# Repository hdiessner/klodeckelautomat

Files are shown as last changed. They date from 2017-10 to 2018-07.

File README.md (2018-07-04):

# klodeckelautomat
This project serves the purpose to provide remote control of telescope covers that prevent dust from covering the front lense of telescopes.

Hardware requirements:
- Arduino
- Servo motors (one for each moving cover)
- Cover material for covering the front opening of the telescope
- Mounting material to attach the servo to the dew shield of the telescope
- Housing for Arduino
- push buttons for each cover if manual operation is wanted

Software:
- platformio project with code for the Arduino
- .py Python script to control open / close operations via command line
- .html front-end to use a web browser to open / close the cover

# Install python part
 1. Set Port in Winkergrabbe.py
 2. Optional: setup virtuelenv
 3. pip install -r requirements.txt
 4. python Winkergrabbe.py

# Serial commands

| ID | Data | Description |
|----|---|---|
|  0 | Text | Data Acknowledge |
|  1 | Text | Error |
|  2 | Text | Debug Messages |
|  3 | (0..7), (0..255)  | Set Servo x to y |
|  4 | (0..7), State | Store Servo x as pos |
|  5 | (0..2)  New state | Change State |
|  6 | (0..2), State | Telescope to pos |

| ID | State |
|----|---|
| 0  | Close |
| 1  | Open |
| 2  | Bahtinov  |
| 3  | Undefined |

# Pinout

| Pin | Description |
|-----|---|
| 2 | Button 0 |
| 3 | Button 1 |
| 4 | Button 2 |
| 5 | OE |
| A4  | SDA | 
| A5  | SCL |

# Servo description

| Num | Telescope | Purpose |
|-----|---|---|
| 0 | 0 | Cover |
| 1 | 0 | Bahtinov |
| 2 | 1 | Cover Left |
| 3 | 1 | Cover Right |
| 4 | 1 | Bahtinov Left  |
| 5 | 1 | Bahtinov Right |
| 6 | 2 | Cover |
| 7 | 2 | Bahtinov |

Addition in October 2017:
- 3D sketch for 3D printing of a telescope clamp that attaches to the dew shield of an AstroPhysics Starfire 155EDF and that provides the hosuing of a servo.

https://github.com/thijse/Arduino-CmdMessenger/issues/27

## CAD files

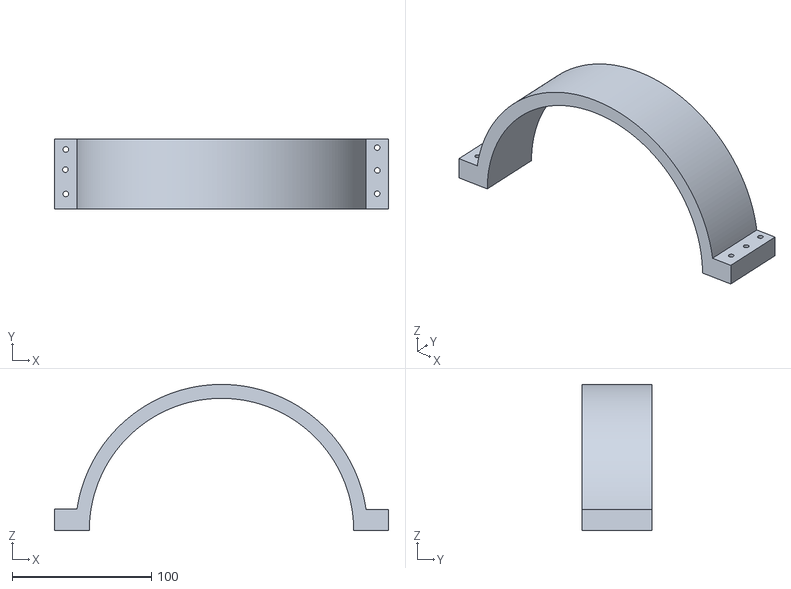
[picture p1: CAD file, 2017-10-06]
3D Design/Starfire155_Clamp_Bottom.stl
240.0 x 50.0 x 105.0

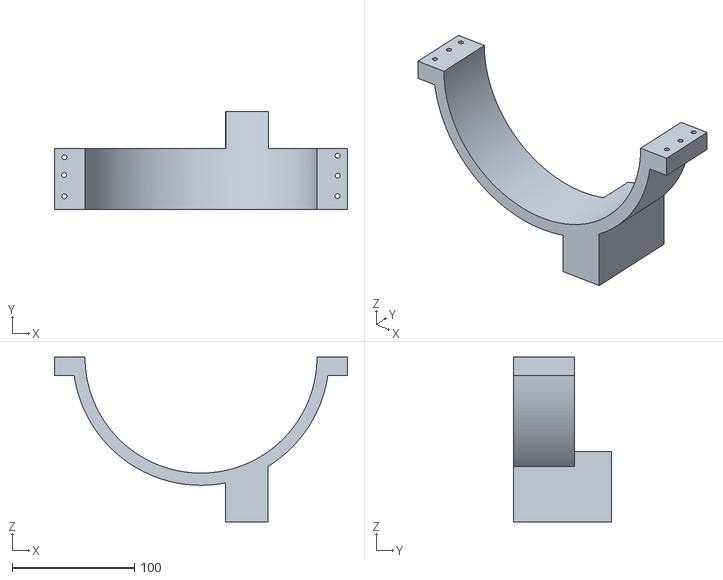
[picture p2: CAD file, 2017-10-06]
3D Design/Starfire155_Clamp_Motor.stl
240.0 x 80.0 x 135.0

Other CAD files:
3D Design/Scopeclamp v3 Motor v3.f3d

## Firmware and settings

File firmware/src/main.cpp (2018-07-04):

#include <Wire.h>
#include <EEPROM.h>
#include <Arduino.h>
#include <CmdMessenger.h>
#include <Adafruit_PWMServoDriver.h>

#define NUM_TELESCOPES   3
#define NUM_SERVOS       8
#define MOVE_WAIT_TIME 800

#define SWITCH_TELE0     2 
#define SWITCH_TELE1     3   
#define SWITCH_TELE2     4

#define OE_PIN           5   

uint16_t                positionsClosed[NUM_SERVOS] = {};
uint16_t                positionsOpen[NUM_SERVOS]   = {};
uint16_t                positionsSet[NUM_SERVOS]    = {};
uint8_t                 telescopeState[3]           = {0, 0, 0}; 
Adafruit_PWMServoDriver pwm                         = Adafruit_PWMServoDriver();
CmdMessenger            cmdMessenger                = CmdMessenger(Serial, ',', ';'); 

enum{                //      Closed     Open
  kAcknowledge,      // 0 
  kError,            // 1
  kDebug,            // 2
  kSetServo,         // 3   3,1,150;     3,1,400;
  kStoreServo,       // 4   4,1,0;       4,1,1;
  kStateChange,      // 5
  kTelescopePosition // 6   6,0,0;       6,0,1;    6,0,2;
};

void storePositions(){
  uint8_t  ee = 0;
  uint8_t* p  = (uint8_t*)(void*)&positionsClosed;

  for (uint8_t i = 0; i < sizeof(positionsClosed); i++){
      EEPROM.write(ee++, *p++);
  }

  ee = 100;
  p  = (uint8_t*)(void*)&positionsOpen;

  for (uint8_t i = 0; i < sizeof(positionsOpen); i++){
      EEPROM.write(ee++, *p++);
  }
  
}

void loadPositions(){

  uint8_t  ee = 0;
  uint8_t* p  = (uint8_t*)(void*)&positionsClosed;

  for (uint8_t i = 0; i < sizeof(positionsClosed); i++){
    *p++ = EEPROM.read(ee++);
  }

  ee = 100;
  p  = (uint8_t*)(void*)&positionsOpen;

  for (uint8_t i = 0; i < sizeof(positionsOpen); i++){
    *p++ = EEPROM.read(ee++);
  }

  // Middel state, we don't know jet
  for (uint8_t i = 0; i < NUM_SERVOS; i++){
    positionsSet[i] = 300; 
  }  

}

void OnSetServo(){
    cmdMessenger.sendCmd(kDebug, "SetServo called");
    uint8_t  servo      = cmdMessenger.readInt16Arg(); 
    uint16_t position   = cmdMessenger.readInt16Arg();
    positionsSet[servo] = position;
    pwm.setPWM(servo, 0, position);
    cmdMessenger.sendCmd(kAcknowledge, "StoreServo moved");
}

void OnStoreServo(){
    cmdMessenger.sendCmd(kDebug, "StoreServo called");
    uint8_t servo = cmdMessenger.readInt16Arg();
    uint8_t state = cmdMessenger.readInt16Arg();

    if (state == 0) {
      positionsClosed[servo] = positionsSet[servo];
    }

    if (state == 1) {
      positionsOpen[servo] = positionsSet[servo];    
    }

    storePositions();
    cmdMessenger.sendCmd(kAcknowledge, "StoreServo stored");
}

void moveToState(uint8_t telescope, uint8_t state){

  if (telescope == 0) {

    if (state == 0){                        // Close
      cmdMessenger.sendCmdStart(kStateChange);  
      cmdMessenger.sendCmdArg(0);    
      cmdMessenger.sendCmdArg(0);    
      cmdMessenger.sendCmdEnd();
      pwm.setPWM(1, 0, positionsOpen[1]);   // Open Bahtinov 
      delay(MOVE_WAIT_TIME);
      pwm.setPWM(0, 0, positionsClosed[0]); // Close Cover 
      delay(MOVE_WAIT_TIME);
      pwm.setPWM(1, 0, positionsClosed[1]); // Close Bahtinov 
      telescopeState[0] = 0;
      
    } else if (state == 1){                 // Open
      cmdMessenger.sendCmdStart(kStateChange);  
      cmdMessenger.sendCmdArg(0);    
      cmdMessenger.sendCmdArg(1);    
      cmdMessenger.sendCmdEnd();
      pwm.setPWM(1, 0, positionsOpen[1]);   // Open Bahtinov
      delay(MOVE_WAIT_TIME);
      pwm.setPWM(0, 0, positionsOpen[0]);   // Open Cover
      telescopeState[0] = 1;

    } else if (state == 2) {                // Bahtinov
      cmdMessenger.sendCmdStart(kStateChange);  
      cmdMessenger.sendCmdArg(0);    
      cmdMessenger.sendCmdArg(2);    
      cmdMessenger.sendCmdEnd();
      pwm.setPWM(1, 0, positionsOpen[1]);   // Open Bahtinov make sure its away
      delay(MOVE_WAIT_TIME);
      pwm.setPWM(0, 0, positionsOpen[0]);   // Open cover
      delay(MOVE_WAIT_TIME);
      pwm.setPWM(1, 0, positionsClosed[1]); // Close Bahtinov 
      telescopeState[0] = 2;
    }

  }

  if (telescope == 1) {

    if (state == 0){                        // Close
      cmdMessenger.sendCmdStart(kStateChange);  
      cmdMessenger.sendCmdArg(1);    
      cmdMessenger.sendCmdArg(0);    
      cmdMessenger.sendCmdEnd();
      pwm.setPWM(4, 0, positionsOpen[4]);   // Open Bahtinov 
      pwm.setPWM(5, 0, positionsOpen[5]);   // Open Bahtinov 
      delay(MOVE_WAIT_TIME);
      pwm.setPWM(2, 0, positionsClosed[2]); // Close Cover 
      pwm.setPWM(3, 0, positionsClosed[3]); // Close Cover 
      delay(MOVE_WAIT_TIME);
      pwm.setPWM(4, 0, positionsClosed[4]); // Close Bahtinov 
      pwm.setPWM(5, 0, positionsClosed[5]); // Close Bahtinov 
      telescopeState[1] = 0;

    } else if (state == 1){                // Open
      cmdMessenger.sendCmdStart(kStateChange);  
      cmdMessenger.sendCmdArg(1);    
      cmdMessenger.sendCmdArg(1);    
      cmdMessenger.sendCmdEnd();
      pwm.setPWM(4, 0, positionsOpen[4]);   // Open Bahtinov make sure its away
      pwm.setPWM(5, 0, positionsOpen[5]);   // Open Bahtinov make sure its away
      delay(MOVE_WAIT_TIME);
      pwm.setPWM(2, 0, positionsOpen[2]);   // Open cover
      pwm.setPWM(3, 0, positionsOpen[3]);   // Open cover
      telescopeState[1] = 1;

    } else if (state == 2) {                // Bahtinov
      cmdMessenger.sendCmdStart(kStateChange);  
      cmdMessenger.sendCmdArg(1);    
      cmdMessenger.sendCmdArg(2);    
      cmdMessenger.sendCmdEnd();
      pwm.setPWM(4, 0, positionsOpen[4]);   // Open Bahtinov make sure its away
      pwm.setPWM(5, 0, positionsOpen[5]);   // Open Bahtinov make sure its away
      delay(MOVE_WAIT_TIME);
      pwm.setPWM(2, 0, positionsOpen[2]);   // Open cover
      pwm.setPWM(3, 0, positionsOpen[3]);   // Open cover
      delay(MOVE_WAIT_TIME);
      pwm.setPWM(4, 0, positionsClosed[4]); // Close Bahtinov 
      pwm.setPWM(5, 0, positionsClosed[5]); // Close Bahtinov 
      telescopeState[1] = 2;
    }

  }

  if (telescope == 2) {

    if (state == 0){                        // Close
      cmdMessenger.sendCmdStart(kStateChange);  
      cmdMessenger.sendCmdArg(2);    
      cmdMessenger.sendCmdArg(0);    
      cmdMessenger.sendCmdEnd();
      pwm.setPWM(7, 0, positionsOpen[7]);   // Open Bahtinov 
      delay(MOVE_WAIT_TIME);
      pwm.setPWM(6, 0, positionsClosed[6]); // Close Cover 
      delay(MOVE_WAIT_TIME);
      pwm.setPWM(7, 0, positionsClosed[7]); // Close Bahtinov 
      telescopeState[2] = 0;

    } else if (state == 1){                 // Open
      cmdMessenger.sendCmdStart(kStateChange);  
      cmdMessenger.sendCmdArg(2);    
      cmdMessenger.sendCmdArg(1);    
      cmdMessenger.sendCmdEnd();
      pwm.setPWM(7, 0, positionsOpen[7]);   // Open Bahtinov make sure its away
      delay(MOVE_WAIT_TIME);
      pwm.setPWM(6, 0, positionsOpen[6]);   // Open Cover
      telescopeState[2] = 1;

    } else if (state == 2) {                // Bahtinow
      cmdMessenger.sendCmdStart(kStateChange);  
      cmdMessenger.sendCmdArg(2);    
      cmdMessenger.sendCmdArg(2);    
      cmdMessenger.sendCmdEnd();
      pwm.setPWM(7, 0, positionsOpen[7]);   // Open Bahtinov make sure its away
      delay(MOVE_WAIT_TIME);
      pwm.setPWM(6, 0, positionsOpen[6]);   // Open cover
      delay(MOVE_WAIT_TIME);
      pwm.setPWM(7, 0, positionsClosed[7]); // Close Bahtinov 
      telescopeState[2] = 2;
    }
  }

}

void OnTelescopePosition(){
    cmdMessenger.sendCmd(kDebug, "move to position");
    uint8_t telescope = cmdMessenger.readInt16Arg();
       uint8_t state     = cmdMessenger.readInt16Arg();
       moveToState(telescope, state);
       cmdMessenger.sendCmd(kAcknowledge, "position reached");
}   

void attachCommandCallbacks(   ){
  cmdMessenger.attach(kSetServo,          OnSetServo);
  cmdMessenger.attach(kStoreServo,        OnStoreServo);
  cmdMessenger.attach(kTelescopePosition, OnTelescopePosition);
}

void setup() {
  pinMode(SWITCH_TELE0, INPUT_PULLUP);
  pinMode(SWITCH_TELE1, INPUT_PULLUP);
  pinMode(SWITCH_TELE2, INPUT_PULLUP);
  pinMode(OE_PIN,       OUTPUT);
  digitalWrite(OE_PIN,  HIGH); // disable

  Serial.begin(9600);
  cmdMessenger.printLfCr(true);
  attachCommandCallbacks();
  cmdMessenger.sendCmd(kDebug, "Arduino ready!");

  loadPositions();

  pwm.begin();  
  pwm.setPWMFreq(60);        // Analog servos run at ~60 Hz updates
  digitalWrite(OE_PIN, LOW); // enable

}

void loop() {  
  cmdMessenger.feedinSerialData();

  if(!digitalRead(SWITCH_TELE0)){
    moveToState(0, (telescopeState[0] + 1) % 3);
  }

  if(!digitalRead(SWITCH_TELE1)){
    moveToState(1, (telescopeState[1] + 1) % 3);
  }

  if(!digitalRead(SWITCH_TELE2)){
    moveToState(2, (telescopeState[2] + 1) % 3); 
  }

}

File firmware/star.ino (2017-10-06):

#include <Servo.h>
#include <CmdMessenger.h>

#define S1PIN           3
#define S2PIN           9
#define S3PIN           6
#define S4PIN           7
#define SWITCH1PIN      8
#define SWITCH2PIN      4
#define SWITCH3PIN      5

#define LIGHTPIN        2 // Internal Used by frequency counter
#define LIGHTDELAY 300000

Servo             myservo;
CmdMessenger      cmdMessenger     = CmdMessenger(Serial, ',', ';'); 
uint32_t          lcdcounter       = 1000000000;
bool              shutterclosed[4] = {true, true, true, true};
uint8_t           openval[4]       = {100, 100, 100, 100};
uint8_t           closeval[4]      = { 30,  10,  30,  30};
uint8_t           pins[4]          = {S1PIN, S2PIN, S3PIN, S4PIN};
volatile uint32_t lightCounter     = 0;

enum{
  kAcknowledge, // 0 
  kError,       // 1
  kLDR,         // 2
  kS1,          // 3
  kS2,          // 4
  kS3,          // 5
  kS4,          // 6
  kSOpen,       // 7
  kSClose,      // 8
};

void OnS1(){
  int8_t val = cmdMessenger.readInt16Arg();
  setServo(0, val );
}

void OnS2(){
  int8_t val = cmdMessenger.readInt16Arg();
  setServo(1, val);  
}

void OnS3(){
  int8_t val = cmdMessenger.readInt16Arg();
  setServo(2, val);
}

void OnS4(){
  int8_t val = cmdMessenger.readInt16Arg();
  setServo(3, val);
}

void attachCommandCallbacks(){
  cmdMessenger.attach(OnUnknownCommand);
  cmdMessenger.attach(kS1, OnS1);
  cmdMessenger.attach(kS2, OnS2);
  cmdMessenger.attach(kS3, OnS3);
  cmdMessenger.attach(kS4, OnS4);
}

void OnUnknownCommand(){
  cmdMessenger.sendCmd(kError,"Command without attached callback");
}

void lightTick(){
  lightCounter++;
}

uint16_t getLDR(void){
  lightCounter = 0;
  attachInterrupt(digitalPinToInterrupt(LIGHTPIN), lightTick, RISING);  
  delay(1000);
  detachInterrupt(digitalPinToInterrupt(LIGHTPIN));
  return lightCounter;
}

void setServo(uint8_t pin, uint8_t pos){  
  if (pos > 45){
    openval[pin] = pos;
    shutterclosed[pin] = false;
    cmdMessenger.sendCmd(kSOpen, pin);
  }else{
    closeval[pin] = pos;
    shutterclosed[pin]  = true;
    cmdMessenger.sendCmd(kSClose, pin);
  }
  myservo.attach(pins[pin]);  
  myservo.write(pos);    
  delay(1500);
  pinMode(pins[pin], INPUT);  
}

void setup() {
  pinMode(S1PIN, INPUT);
  pinMode(S2PIN, INPUT);
  pinMode(S3PIN, INPUT);
  pinMode(S4PIN, INPUT);

  pinMode(SWITCH1PIN, INPUT_PULLUP);
  pinMode(SWITCH2PIN, INPUT_PULLUP);
  pinMode(SWITCH3PIN, INPUT_PULLUP);

  Serial.begin(9600);
  cmdMessenger.printLfCr(true);
  attachCommandCallbacks();
  cmdMessenger.sendCmd(kAcknowledge, "Arduino ready!");

}

void loop() {  
  cmdMessenger.feedinSerialData();

  if(!digitalRead(SWITCH1PIN)){
    if(shutterclosed[0]){
      setServo(0, openval[0]);
      shutterclosed[0] = false;
    }else{
      setServo(0, closeval[0]);
      shutterclosed[0] = true;      
    }
  }

  if(!digitalRead(SWITCH2PIN)){
    if(shutterclosed[1]){
      setServo(1, openval[1]);
      shutterclosed[1] = false;
    }else{
      setServo(1, closeval[1]);
      shutterclosed[1] = true;      
    }    
  }

  if(!digitalRead(SWITCH3PIN)){
    if(shutterclosed[2]){
      setServo(2, openval[2]);
      shutterclosed[2] = false;
    }else{
      setServo(2, closeval[2]);
      shutterclosed[2] = true;      
    }
    if(shutterclosed[3]){
      setServo(3, openval[3]);
      shutterclosed[3] = false;
    }else{
      setServo(3, closeval[3]);
      shutterclosed[3] = true;      
    }
  }

  if(lcdcounter++ > LIGHTDELAY){
    cmdMessenger.sendCmd(kLDR, getLDR());
    lcdcounter = 0;
  }
  
}

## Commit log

2018-06-28 Sorting in folders
    [Scopeclamp v3 Motor v3.f3d, Starfire155_Clamp_Bottom.stl, Starfire155_Clamp_Motor.stl]
2018-07-01 Adding PWM Servo lib
2018-07-03 Servo description
2018-07-03 Defining switches and switch functions
2018-07-03 Ack button press
2018-07-03 Fixing button init
2018-07-03 Buttons and commands fixed
    [main.cpp]
2018-07-03 Remove wrong StateChange updates
    [main.cpp]
